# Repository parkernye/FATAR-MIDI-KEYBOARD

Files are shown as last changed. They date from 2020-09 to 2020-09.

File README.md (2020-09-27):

# FATAR-MIDI-KEYBOARD
 Daughter board for fatar keybed.
 
[FATAR](http://www.fatar.com/) makes an extremely rugged 44-key keyboard with weighted keys. It is the most natural feeling key-bed that resembles an actual grand paino in a small footprint. 

The goal of this project is to use this keybed as a user interface a future modular synth. It follows the [midi protocol](https://en.wikipedia.org/wiki/MIDI) and then is HEAVILY influenced by [elkayem's midi2cv project](https://github.com/elkayem/midi2cv) to convert this midi signal to various control voltages. It is all ported onto a single PCB which connects directly to the prexisting fatar pcb. 

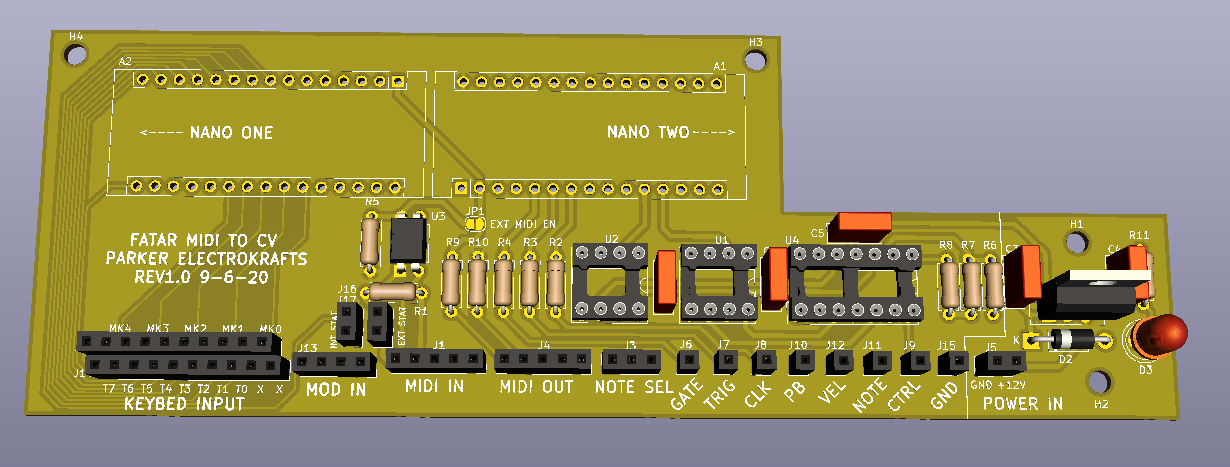
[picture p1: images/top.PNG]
TOP-side

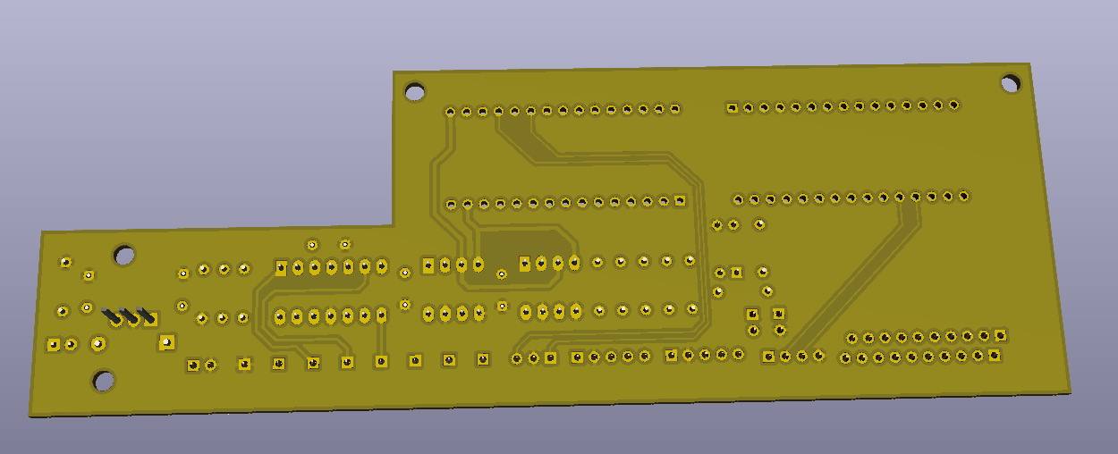
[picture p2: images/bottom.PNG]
BOTTOM-side

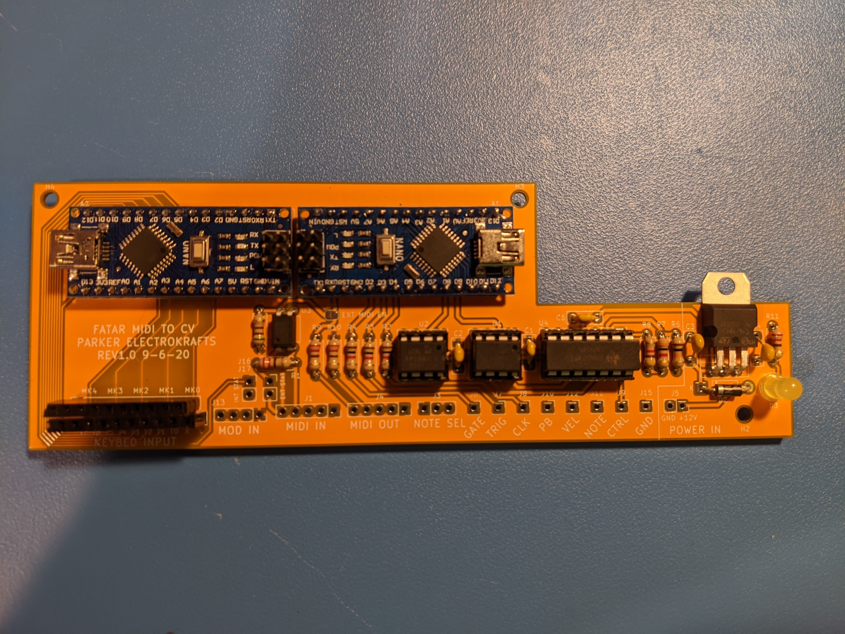
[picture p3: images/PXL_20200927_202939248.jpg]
Populated Board


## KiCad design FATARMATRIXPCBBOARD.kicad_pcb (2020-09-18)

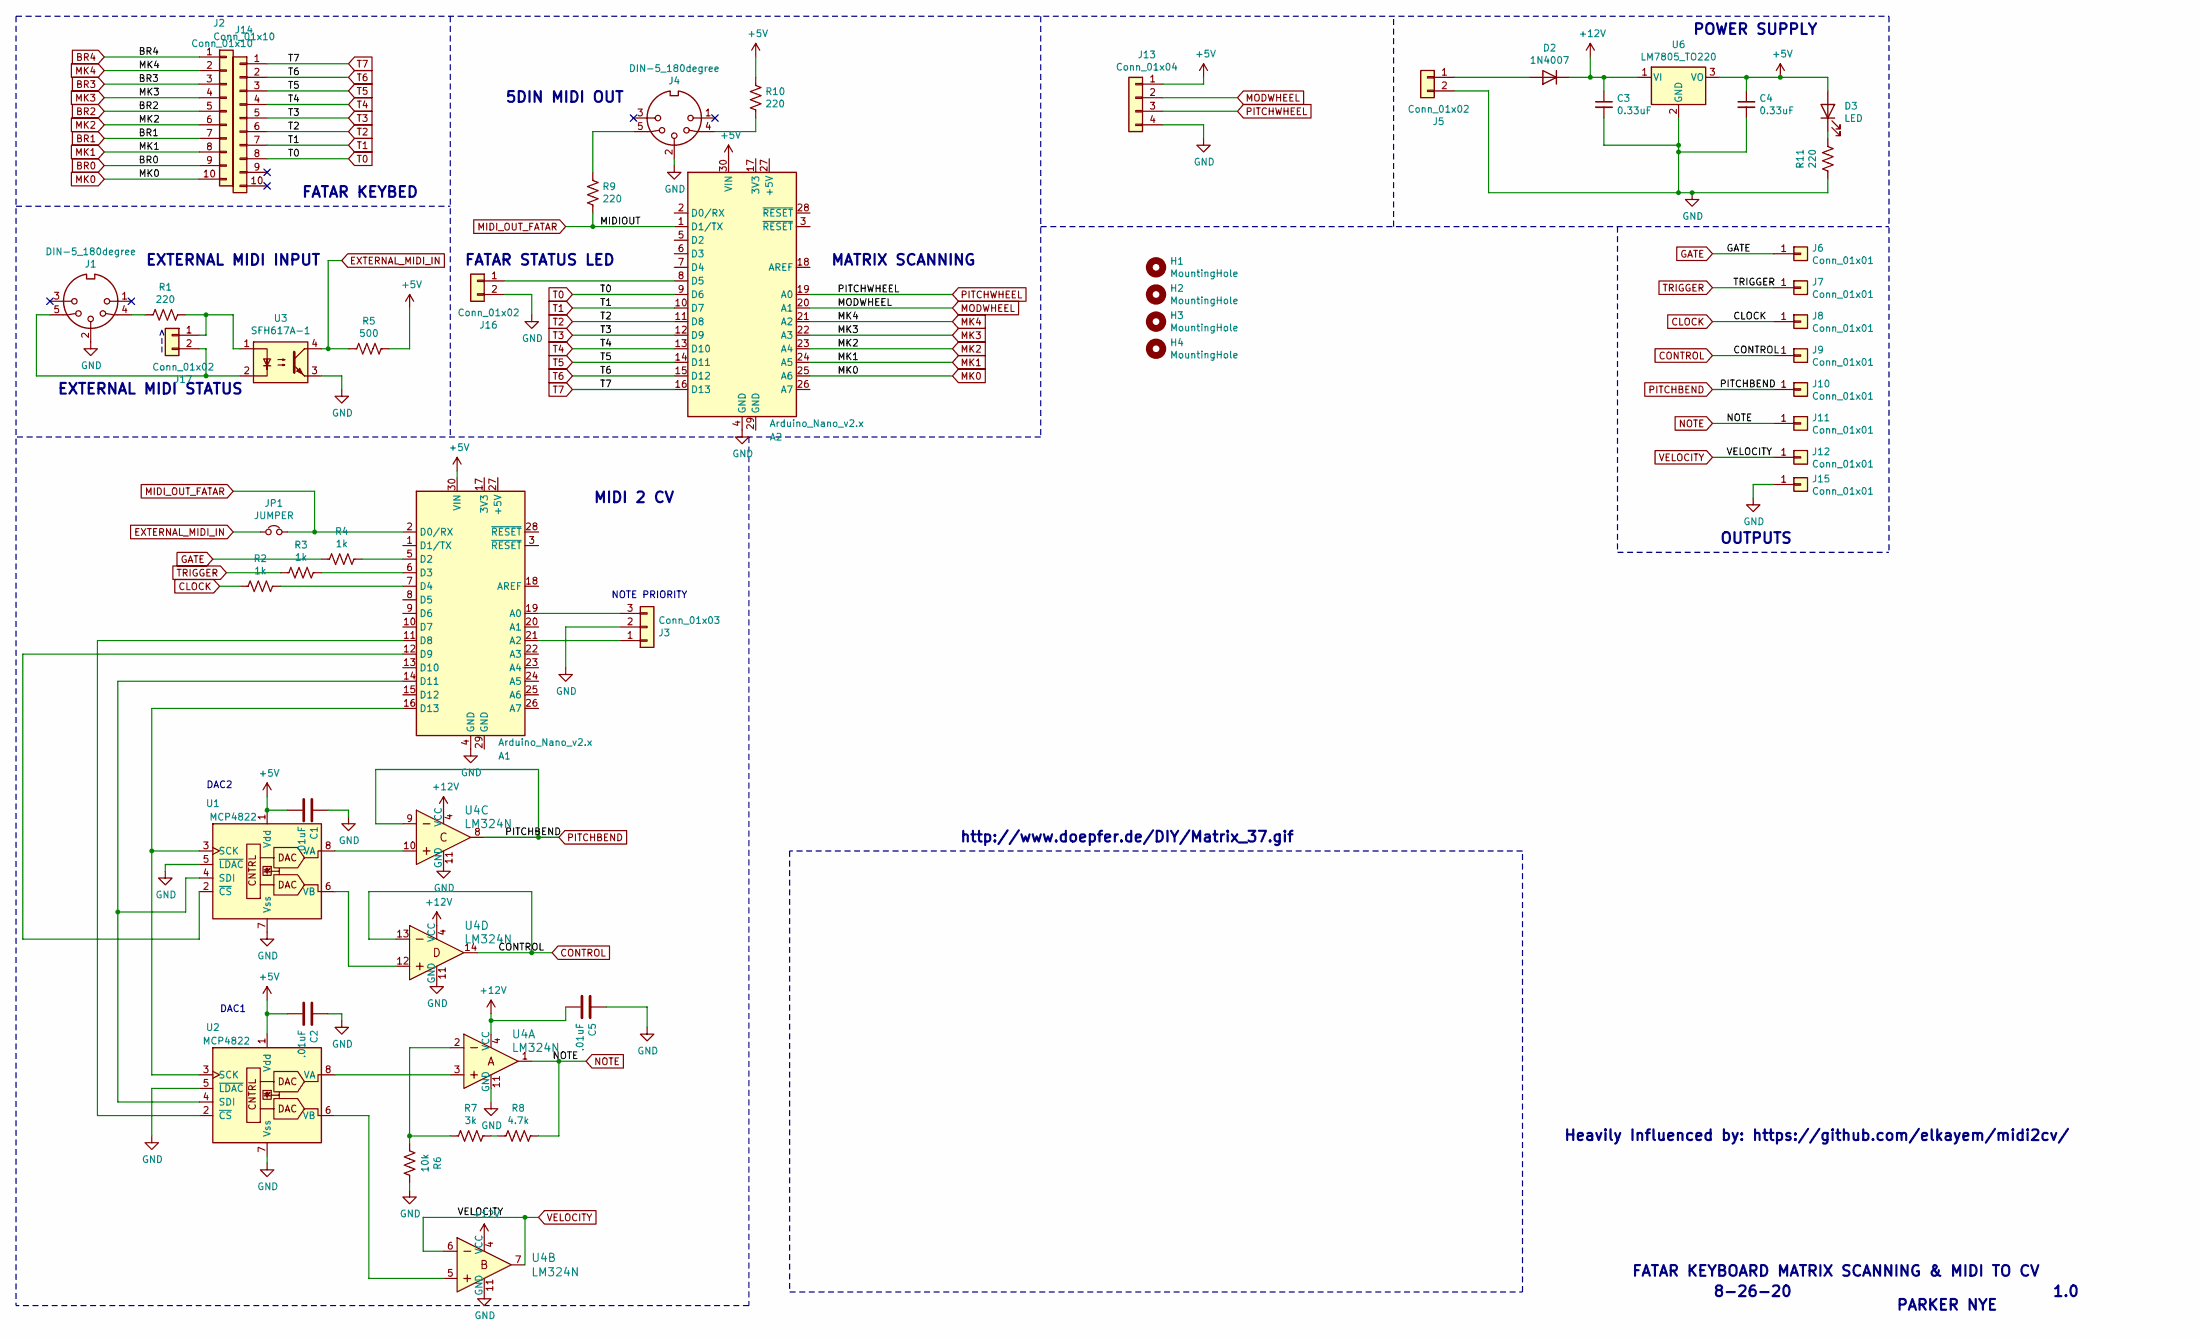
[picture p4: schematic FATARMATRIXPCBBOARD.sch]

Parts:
A1, A2: Arduino_Nano_v2.x; Arduino_Nano
C1, C2, C5: .01uF; C_Rect_L7.2mm_W2.5mm_P5.00mm_FKS2_FKP2_MKS2_MKP2
C3, C4: 0.33uF; C_Rect_L7.2mm_W2.5mm_P5.00mm_FKS2_FKP2_MKS2_MKP2
D2: 1N4007; D_DO-41_SOD81_P10.16mm_Horizontal
D3: LED; LED_D5.0mm
H1, H2, H3, H4: MountingHole; MountingHole_3mm
J1, J4: DIN-5_180degree; PinSocket_1x05_P2.54mm_Vertical
J2, J14: Conn_01x10; PinSocket_1x10_P2.54mm_Vertical
J3: Conn_01x03; PinSocket_1x03_P2.54mm_Vertical
J5, J16, J17: Conn_01x02; PinSocket_1x02_P2.54mm_Vertical
J6, J7, J8, J9, J10, J11, J12, J15: Conn_01x01; PinSocket_1x01_P2.54mm_Vertical
J13: Conn_01x04; PinSocket_1x04_P2.54mm_Vertical
JP1: JUMPER; SolderJumper-2_P1.3mm_Open_RoundedPad1.0x1.5mm
R1, R9, R10, R11: 220; R_Axial_DIN0207_L6.3mm_D2.5mm_P7.62mm_Horizontal
R2, R3, R4: 1k; R_Axial_DIN0207_L6.3mm_D2.5mm_P7.62mm_Horizontal
R5: 500; R_Axial_DIN0207_L6.3mm_D2.5mm_P7.62mm_Horizontal
R6: 10k; R_Axial_DIN0207_L6.3mm_D2.5mm_P7.62mm_Horizontal
R7: 3k; R_Axial_DIN0207_L6.3mm_D2.5mm_P7.62mm_Horizontal
R8: 4.7k; R_Axial_DIN0207_L6.3mm_D2.5mm_P7.62mm_Horizontal
U1, U2: MCP4822; DIP-8_W7.62mm_Socket_LongPads
U3: SFH617A-1; DIP-4_W7.62mm
U4: LM324N; DIP-14_W7.62mm_Socket_LongPads; MPN LM324N; Digi-Key_PN 296-1391-5-ND
U6: LM7805_TO220; TO-220-3_Vertical

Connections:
+5V: A1.30 (VIN), A2.30 (VIN), C1.2, C2.2, C4.1, D3.2 (A), J13.1, R5.2, R10.1, U1.1 (Vdd), U2.1 (Vdd), U6.3 (VO)
+12V: C3.1, C5.2, D2.1 (K), U4.4 (VCC), U6.1 (VI)
BR0: J2.9
BR1: J2.7
BR2: J2.5
BR3: J2.3
BR4: J2.1
CLOCK: J8.1, R2.1
CONTROL: J9.1, U4.13, U4.14
EXTERNAL_MIDI_IN: JP1.1, R5.1, U3.4
GATE: J6.1, R4.1
GND: A1.4 (GND), A2.4 (GND), C1.1, C2.1, C3.2, C4.2, C5.1, J1.2, J3.2, J4.2, J5.2, J13.4, J15.1, J16.2, R6.2, R11.1, U1.5 (~LDAC), U1.7 (Vss), U2.5 (~LDAC), U2.7 (Vss), U3.3, U4.11 (GND), U6.2 (GND)
MIDI_OUT_FATAR: A1.2 (D0/RX), A2.1 (D1/TX), JP1.2, R9.2
MK0: A2.25 (A6), J2.10
MK1: A2.24 (A5), J2.8
MK2: A2.23 (A4), J2.6
MK3: A2.22 (A3), J2.4
MK4: A2.21 (A2), J2.2
MODWHEEL: A2.20 (A1), J13.2
NOTE: J11.1, R8.2, U4.1
unnamed: A1.5 (D2), R4.2
unnamed: A1.6 (D3), R3.2
unnamed: A1.7 (D4), R2.2
unnamed: A1.11 (D8), U2.2 (~CS)
unnamed: A1.12 (D9), U1.2 (~CS)
unnamed: A1.14 (D11), U1.4 (SDI), U2.4 (SDI)
unnamed: A1.16 (D13), U1.3 (SCK), U2.3 (SCK)
unnamed: A1.19 (A0), J3.3
unnamed: A1.21 (A2), J3.1
unnamed: A2.8 (D5), J16.1
unnamed: D2.2 (A), J5.1
unnamed: D3.1 (K), R11.2
unnamed: J1.4, R1.1
unnamed: J1.5, J17.2, U3.2
unnamed: J4.4, R10.2
unnamed: J4.5, R9.1
unnamed: J17.1, R1.2, U3.1
unnamed: R6.1, R7.1, U4.2
unnamed: R7.2, R8.1
unnamed: U1.6 (VB), U4.12
unnamed: U1.8 (VA), U4.10
unnamed: U2.6 (VB), U4.5
unnamed: U2.8 (VA), U4.3
PITCHBEND: J10.1, U4.8, U4.9
PITCHWHEEL: A2.19 (A0), J13.3
T0: A2.9 (D6), J14.8
T1: A2.10 (D7), J14.7
T2: A2.11 (D8), J14.6
T3: A2.12 (D9), J14.5
T4: A2.13 (D10), J14.4
T5: A2.14 (D11), J14.3
T6: A2.15 (D12), J14.2
T7: A2.16 (D13), J14.1
TRIGGER: J7.1, R3.1
VELOCITY: J12.1, U4.6, U4.7

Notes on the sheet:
FATAR KEYBED
EXTERNAL MIDI INPUT
POWER SUPPLY
DAC1
NOTE PRIORITY
DAC2
MATRIX SCANNING
MIDI 2 CV
OUTPUTS
FATAR KEYBOARD MATRIX SCANNING & MIDI TO CV
8-26-20
1.0
PARKER NYE
Heavily Influenced by: https://github.com/elkayem/midi2cv/
http://www.doepfer.de/DIY/Matrix_37.gif
5DIN MIDI OUT
FATAR STATUS LED
EXTERNAL MIDI STATUS
-->

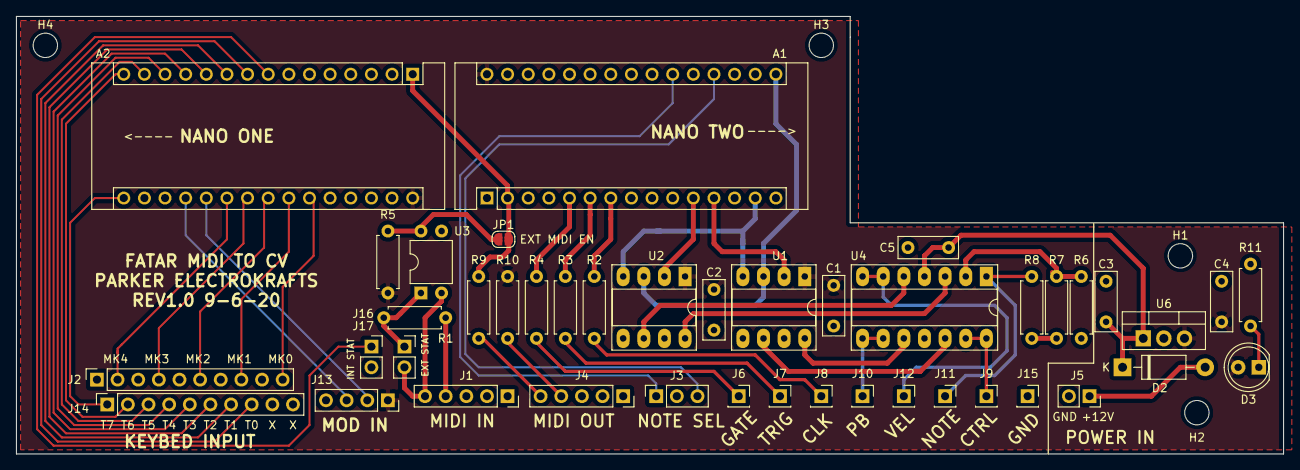
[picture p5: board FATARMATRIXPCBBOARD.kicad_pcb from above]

Board: 2 copper layers, 156.0 x 53.8 mm, 47 parts (0 on the bottom side), 50 nets.

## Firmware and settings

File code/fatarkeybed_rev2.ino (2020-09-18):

/*
Parker Nye 
9-17-2020

CREDITS
Written by tttapa, 24/09/2017
https://github.com/tttapa/MIDI_controller
*/

#include "MIDI_Controller.h" // Include the library

USBDebugMIDI_Interface midiInterface(31250);


//debug
//auto &serial = Serial;
//HardwareSerialMIDI_Interface midi = {Serial1, MIDI_BAUD};


const uint8_t velocity = 0b1111111; // Maximum velocity (0b1111111 = 0x7F = 127)
const uint8_t addresses[5][8] = {   // the note numbers corresponding to the buttons in the matrix
  {57,58,59,60,61,62,63,64},
{65,66,67,68,69,70,71,72},
{73,74,75,76,77,78,79,80}, //why is this keybed offst by 3 notes? 
{81,82,83,84,85,86,87,88},
{89,90,91,92,93,94,95,96}
};

//scan matrix
ButtonMatrix<5, 8> buttonmatrix({18,15,14,16,10}, {2,3,4,5,6,7,8,9}, addresses, 1, velocity);

//pitch and mod wheel
//AnalogHiRes pitch(A0, 1);
//Analog mod(A1, MIDI_CC::Channel_Volume, 1);

void setup() {}

void loop() {
  // Refresh the buttons (check whether the states have changed since last time, if so, send it over MIDI)
  MIDI_Controller.refresh();
}

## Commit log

2020-09-18 init commit
    [FATARMATRIXPCBBOARD-B_Cu.gbr, FATARMATRIXPCBBOARD-B_Mask.gbr, FATARMATRIXPCBBOARD-B_Paste.gbr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]
2020-09-18 added pictures
    [FATARMATRIXPCBBOARD-B_Cu.gbr, FATARMATRIXPCBBOARD-B_Mask.gbr, FATARMATRIXPCBBOARD-B_Paste.gbr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]
